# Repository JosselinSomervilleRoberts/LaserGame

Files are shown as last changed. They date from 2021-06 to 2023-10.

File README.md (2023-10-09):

# LaserGame

For more details about the project, please visit: https://josselinsomervilleroberts.github.io/


<br>

## Auteur

Josselin SOMERVILLE ROBERTS

<br><br>

## Câblage

### Pistolet

| Pin | Valeur du pin dans Arduino | Nom de la variable | Composant |
| --- | --- | --- | --- |
| D0  | 16 | buttons[0] | Bouton 1: **Gachette** |
| D1  | 5 | - | I2C Ecran |
| D2  | 4 | - | I2C Ecran |
| D3  | 0 | buttons[2] | Bouton 3: **Noir** |
| D4  | 2 | buttons[1] | Bouton 2: **Rouge** |
| D5  | 14 | laser | Laser de visée |
| D6  | 12 | kIrLed | Led IR de tir |
| D7  | 13 | df_player | Pin d'envoi de données au DF Player (le pin de réception n'est pas utilisé par manque de pins) |
| D8  | 15 | led | Led de connexion |
| A0  | A0 | - | Bouton 0: **Bleu** |

### Plastron

| Pin | Valeur du pin dans Arduino | Nom de la variable | Composant |
| --- | --- | --- | --- |
| D2  | 4 | ledPin | Bandeau Led |
| D4  | 2 | krecvPin | Récepteur IR |
| D5  | 14 | led1 | Led **Rouge** *(plastron allumé)* |
| D6  | 12 | led2 | Led **Verte** *(vivant)* |
| D7  | 13 | led3 | Led **Bleue** *(connexion)* |

## <br><br>

## Communication

### Communication IR

Les pistolets doivent être identifiables à la fois par **leur adresse MAC** mais également par **le code IR qu'ils envoient**. Comme tous les pistolets partagent les mêmes 3 premiers octets pour leurs adresses MAC, il suffit d'envoyer que les 3 derniers. On peut facilement envoyer 4 octets en IR, on envoie donc les 3 derniers octets de l'adresse MAC du pistolet suivit de ***0x66*** permettant d'identifier qu'il s'agit d'un pistolet du jeu.**

<br>

### Communcation WiFi

#### Structure des messages

Les messages sont seulement composés de :

- l'adresse MAC de l'expéditeur

- un identifiant *(idMessage)*

- une valeur *(value - optionnelle)*

#### Liste des messages

| idMessage ***(uint8_t)*** | value ***(uint32_t)*** | Expéditeur | Récepteur | Decription |
| --- | --- | --- | --- | --- |
| 1 | Couleur **hue** de la cible | Cible avant | Pistolet | Demande de nouvelle connexion. |
| 2 | **Confirmation :** - 1=acceptée ; <br/>- 2=refusée | Pistolet | Cible avant | **Réponse** à une demande de nouvelle connexion ***(id 1)***. |
| 3 | 3 derniers octets de l'adresse MAC du pistolet | Cible avant | Cible arrière | Indique à la cible secondaire de demander à se connecter à un pistolet (suite à une confirmation de connexion ***(id 2)***). |
| 4 | - | Cible avant / Cible arrière | Pistolet | Demande de reconnexion (notamment quand on rallume une cible). |
| 5 | Temps en secondes | Pistolet | Cible avant / Cible arrière | Vérification que la connexion pistolet - cible est toujours active. |
| 6 | Temps en seconde | Cible avant / Cible arrière | Pistolet | **Réponse** à demande de vérification de la validité de la connexion ***(id 5)***. La valeur ens econdes sert à vérifier qu'on obtient bien la confirmation de la denière demande. (si après une demande à *t=17s* on obtient une confirmation pour *t=13s*, il y a un problème : *lag de 4s.*). |
| 7 | - | Pistolet | Cible avant / Cible arrière | Demande de reconnexion (notamment quand onr allume le pistolet). |
| 8 | Couleur **hue** de la cible | Cible avant / Cible arrière | Pistolet | **Réponse** à la demande de reconnexion du pistolet ***(id 7)*** : la reconnexion ets acceptée. |
| 9 | Couleur **hue** de la cible | Pistolet | Cible avant / Cible arrière | Le pistolet a fait un choix d'équipe *(et donc les cibles doivent potentiellement changer de couleur)*. |
| 10 | 3 derniers octets de l'adresse MAC du pistolet qui a touché puis un octer qui vaut 1 si c'est la cible avant, 2 sinon | Cible avant / Cible arrière | Pistolet | Cible touchée. |
| 11 | - | Pistolet | Cible avant / Cible arrière | Mourir. |
| 12 | - | Pistolet | Cible avant / Cible arrière | Revivre. |
| 13 | - | Cible avant / Cible arrière | L'autre cible | Demande de si l'autre cible est connectée à un pistolet ou non *(si quand on rallume la cible, elle n'a pas de pistolet en mémoire, elle peut demander à l'autre cible si elle est déja connectée à un pistolet)*. |
| 14 | - 1SB: couleur **hue**<br/>- 2LSB(1/2): hasBeenConnected?<br/>- 2LSB(2/2): equipeChosen? | Cible avant / Cible arrière | L'autre cible | **Réponse** à la demande si la cible a été connectée à un pistolet ***(id 13)***. |
| 20 | Couleur **hue** de la cible | Pistolet | Cible avant / Cible arrière | Changement de couleur *(sans confirmation du choix d'équipe contrairement à **(id 9)**)*. |
| 30 | - 1: pour commencer<br/>- 2: pour finir | Pistolet **principal** | Autres pîstolets | Changement d'état de la partie. |
| 31 | - 1: pour commencer<br/>- 2: pour finir | Pistolet | Cible avant / Cible arrière | Changement d'état de la partie. |
| 35 | RANDOM JUNK ATM | Pistolet touché | Pistolet qui a touché | Avoir tué quelqu'un. |
| 40 | Nombre de respawns max | Pistolet **principal** | Autres pistolets | **Changement de règle:** nombre de respawns max. |
| 41 | Nombre de morts définitives max | Pistolet **principal** | Autres pistolets | **Changement de règle:** nombre de morts définitives max. |
| 42 | Temps de respawn ***(en secondes)*** | Pistolet **principal** | Autres pistolets | **Changement de règle:** temps de respawn. |
| 43 | Temps de jeu ***(en minutes)*** | Pistolet **principal** | Autres pistolets | **Changement de règle:** temps d'une partie. |
| 44 | - 0: Plastrons allumés<br/>- 1: Plastrons éteints | Pistolet **principal** | Autres pistolets | **Changement de règle:** allumage des lumières des plastrons. |
| 45 | - 0: Plastrons allumés<br/>- 1: Plastrons éteints | Pistolet | Cible avant / Cible arrière | Eteindre ou allumer la lumière des plastrons. |
| 50 | - | Pistolet | Cible avant / Cible arrière | Déconnexion. |
| 60 | Couleur **hue** de la cible | Pisotlet **admin** | Autres pistolets | **DOOM:** OS tous les adversaires (un joueur est considéré adversaire s'il a une couleur **hue** différente de celle envoyée par le pistolet admin) |

<br><br>

## Stockage des données

    Certaines données sont stockées dans la **mémoire EEPROM** afin d'être conservée même si la carte est éteinte. Cela sert notamment a restaurer la connexion si le pistolet ou une cible s'éteint et à s'assurer qu'un joueur ne triche pas en éteignant osn pistolet pour récupérer toute sa vie. Cela permet également de stocker les paramètres de la partie *(temps de respawn, nombre de respawns max, ...)*. Enfin certaines données ***statiques*** sont stockées dans cette mémoire *(id du pistolet, adresse MAC, numéro des musiques, ...)*. Cela permet de ne pas avoir à changer dans le programme certaines variables comme l'identifiant d'un pistolet et ainsi d'avoir un seul programme pour tous les pistolets et un autre pour toutes les cibles (avant et arrière).

    Le score était enregistré mais cette fonctionnalité n'est plus utilisée étant donnée que la comptabilisation du score est désactivée pour une meilleure réception des signaux IR.

    Il faut bien faire attention à ne pas enregistrer trop souvent des données dans la mémoire EEPROM car sa durée de vie est limitée (entre 100 000 et 1 000 000 d'enregistrements pour chaque octets).

<br>

### Pistolet

| Plage d'octets (inclus) | Variable stockée |
| --- | --- |
| 0 - 5 | **Adresse MAC** du pistolet |
| 6 - 11 | **Adresse MAC** de la dernière cible avant connectée |
| 12 - 17 | **Adresse MAC** de la dernière cible arrière connectée |
| 18 - 23 | **Adresse MAC** du dernier pistolet secondaire connecté ***UNUSED*** |
| 24 - 29 | **Adresse MAC** du pistolet de référence ***UNUSED*** |
| 30 | ID du pistolet |
| 31 | ID du pistolet principal *(référence)* ***UNUSED*** |
| 98 | **Etat partie :** Role *(principal / secondaire)*  ***UNUSED*** |
| 99 | **Etat partie :** ID de l'équipe |
| 100 | **Etat partie :** Partie commencée ? |
| 101 - 172 | **Score :** Pattern x8 :<br/>- 101: Nombre de tirs sur le joueur 1 - cible avant<br/>- 102: Nombre de tirs sur le joueur 1 - cible avant - pistolet secondaire<br/>- 103: Nombre de tirs sur le joueur 1 - cible arrière<br/>- 104: Nombre de tirs sur le joueur 1 - cible arrière - pistolet secondaire<br/>- 105: Nombre de fois touché par joueur 1 cible avant<br/>- 106: Nombre de fois touché par joueur 1 cible avant - pistolet secondaire<br/>- 107: Nombre de fois touché par joueur 1 cible arrière<br/>- 108: Nombre de fois touché par joueur 1 cible arrière - pistolet secondaire<br/>***UNUSED*** |
| 189 | **Setting :** Admin ? |
| 190 | **Cheat :** Invincible ? |
| 191 | **Cheat :** Munitions illimités ? |
| 192 | **Cheat :** Tir rapide ? **NOT WORKING** |
| 193 | **Règle :** Nombre de respawns max |
| 194 | **Règle :** Nombre de morts définitives max |
| 195 | **Règle :** Délai de respawn *(en secondes)* |
| 196 | **Règle :** Duréed'une partie *(en minutes)* |
| 197 | **Règle :** Lumières des plastons allumées ? |
| 198 | **Etat partie :** Nombre de vies du joueur |
| 199 | **Etat partie :** Nombre de respawns restants du joueur |
| 200 | **Etat partie :** Nombre de morts définitives restantes du joueur |
| 201 - 229 | Numéro des 28 musiques ***(la numérotation diffère pour certains DF players, d'ou l'intéret)*** |

<br>

### Plastron

| Plage d'octets (inclus) | variable stockée |
| --- | --- |
| 0 - 5 | **Adresse MAC** de la cible |
| 6 - 11 | **Adresse MAC** de l'autre cible |
| 12 - 17 | **Adresse MAC** du dernier pistolet connecté |
| 18 - 23 | **Adresse MAC** du dernier psitolet secondaire connecté ***UNUSED*** |
| 24 | Type de la cible<br/>- 1 : AVANT<br/>- 2 : ARRIERE |
| 25 | Couleur **hue** |

<br><br>

## Musiques et effets sonores

    Les effets sonores sont gérés par la carte DF Player qui lit les fichiers MP3 stockés sur la carte SD contenue dans le pistolet. 

    Pour une raison étonnante, certains DF Player ne lisent pas les fichiers dans le bon ordre (normalement *myDFPlayer.play(1)* est censé jouer le morceau *0001.wav* mais ce n'est pas le cas pour tous les modèles). C'est pour ça que l'ordre des musiques est stocké dans le mémoire EEPROM pour chaque pistolet.

    Voici la liste des effets sonores disponibles :

| Fichier *(.wav)* | Effet sonore |
| --- | --- |
| 0001 | Tirer pistoler |
| 0002 | Tirer shotgun |
| 0003 | Tirer laser *(2 s)* |
| 0004 | Tirer pistolet - plus de munitions |
| 0005 | Tirer shotgun - plus de munitions  |
| 0006 | Tirer laser - plus de munitions |
| 0007 | Recharger pistolet |
| 0008 | Recharger shotgun |
| 0009 | Recharger laser |
| 0010 | Toucher ennemi |
| 0011 | Toucher allié |
| 0012 | Perdre une vie |
| 0013 | Mourir |
| 0014 | Revivre |
| 0015 | Gagner une vie |
| 0016 | Le médecin fait revivre quelqu'un  |
| 0017 | Mort définitive |
| 0018 | Début partie |
| 0019 | Fin partie |
| 0020 | Power up 1 |
| 0021 | Power down 1 |
| 0022 | Power up 2 |
| 0023 | Power down 2 |
| 0024 | Power up 3 |
| 0025 | Power down 3 |
| 0026 | Power up 4 |
| 0027 | Power down 4 |
| 0028 | Mort 2 |

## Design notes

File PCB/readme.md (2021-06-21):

# PCB Files

These files were designed on **EasyEDA** by myself.

## SuperCharger

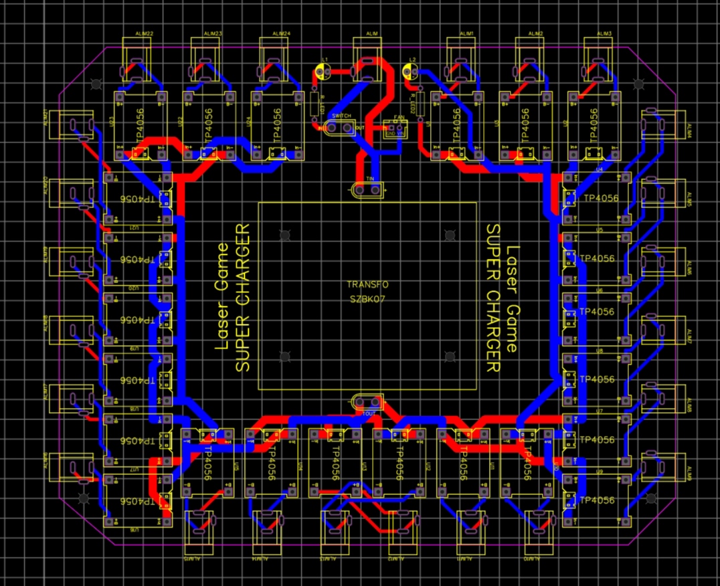
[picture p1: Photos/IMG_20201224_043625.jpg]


## Gun

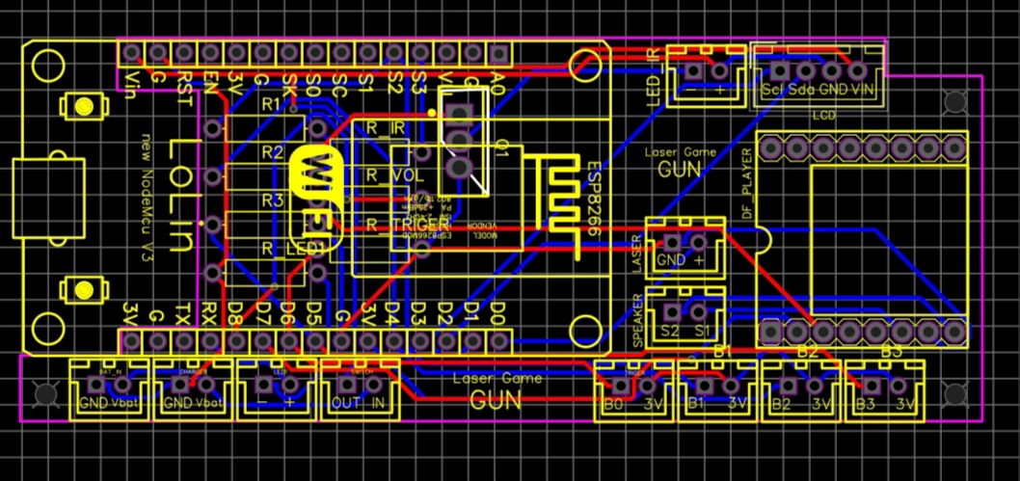
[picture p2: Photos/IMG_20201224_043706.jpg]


## Plastron

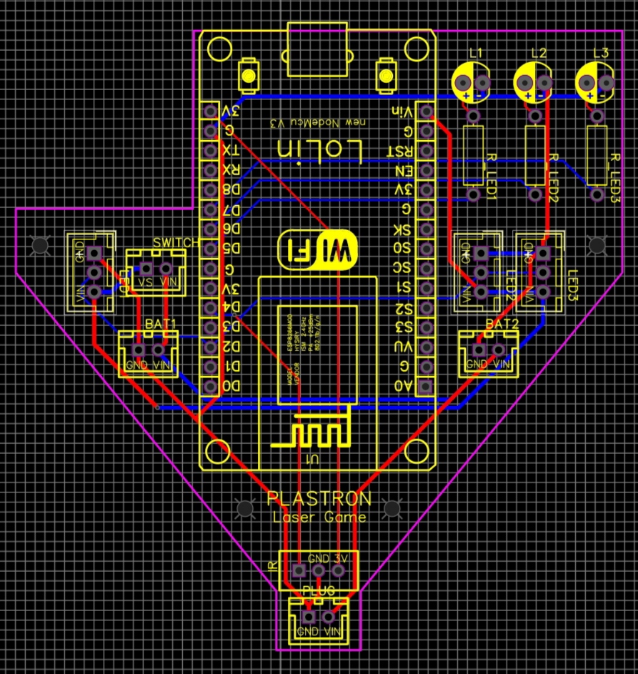
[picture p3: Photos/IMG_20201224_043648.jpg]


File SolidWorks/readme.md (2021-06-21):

# Solidworks Files

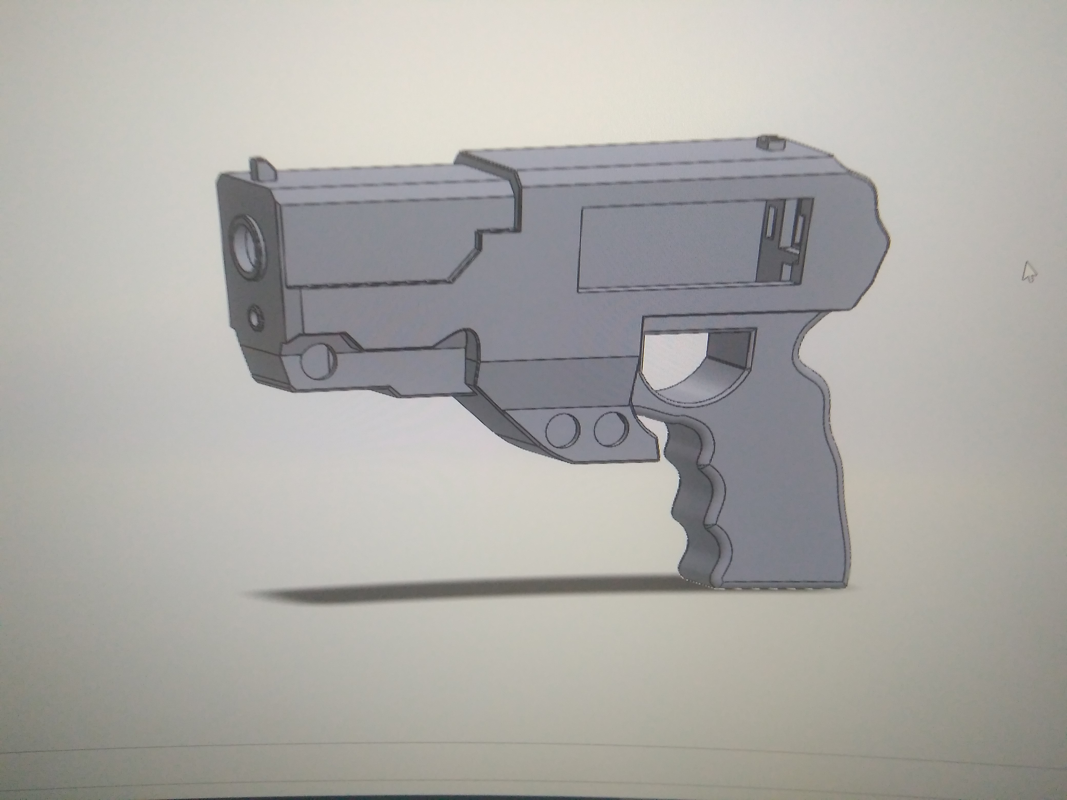
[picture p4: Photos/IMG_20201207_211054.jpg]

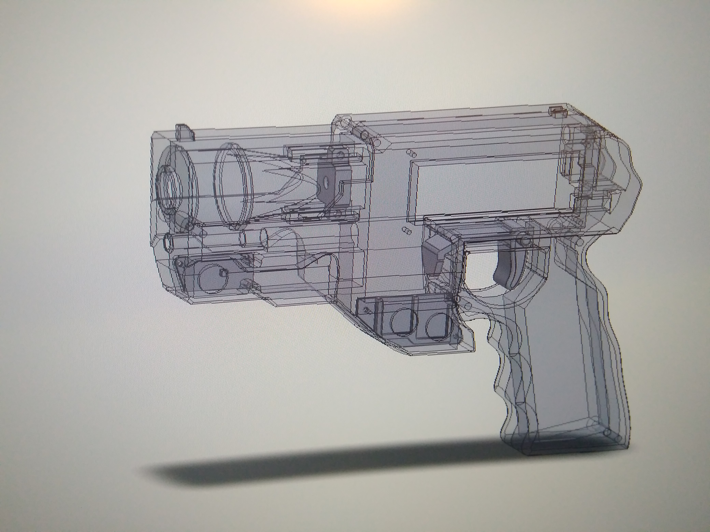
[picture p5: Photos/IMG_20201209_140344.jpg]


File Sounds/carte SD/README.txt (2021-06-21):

0001. Shoot pistolet - 4
0002. Shoot shotgun  - 5
0003. Shoot laser (2sec) - 6

0004. Shoot pistolet - plus de munitions - 7
0005. Shoot shotgun  - plus de munitions - 8
0006. Shoot laser - plus de munitions - 9

0007. Recharger pistolet - 10
0008. Recharger shotgun  - 11
0009. Recharger laser    - 12

0010. Toucher quelqu'un   - 13
0011. Toucher allié       - 14
0012. Perdre une vie      - 15
0013. Mourir              - 16
0014. Revivre             - 17
0015. Gagner une vie      - 18
0016. Medecin fait revivre quelqu'un - 19
0017. Mort du roi                    - 20

0018. Début partie                   - 21
0019. Fin partie                     - 22

0020. Power up 1    - 23
0021. Power down 1  - 24
0022. Power up 2    - 25
0023. Power down 2  - 26
0024. Power up 3    - 27
0025. Power down 3  - 28
0026. Power up 4 - 1
0027. Power down 4 - 2
0028. Mort 2 - 3

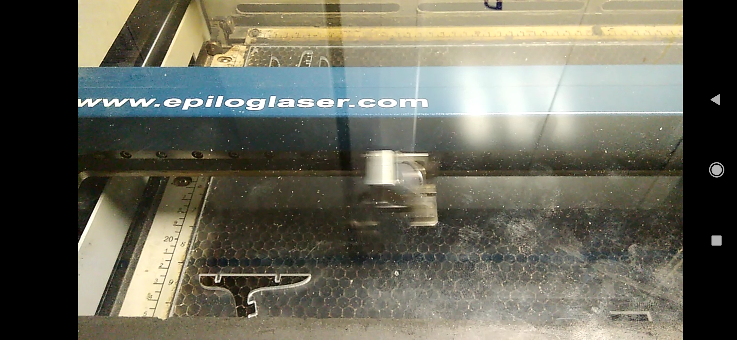
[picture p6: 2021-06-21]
Photos/Screenshot_2020-12-24-04-1.jpg

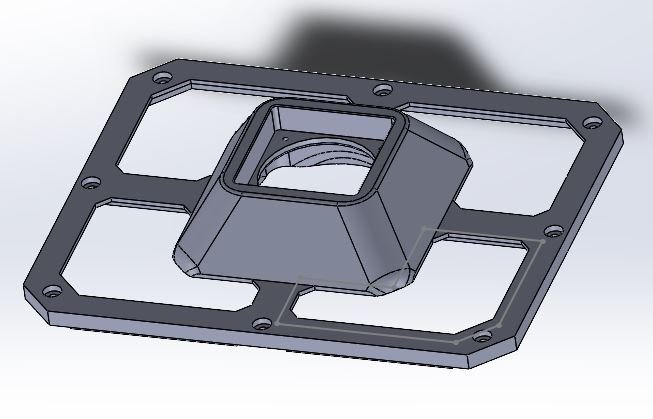
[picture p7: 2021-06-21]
Photos/couvercle_chargeur.JPG

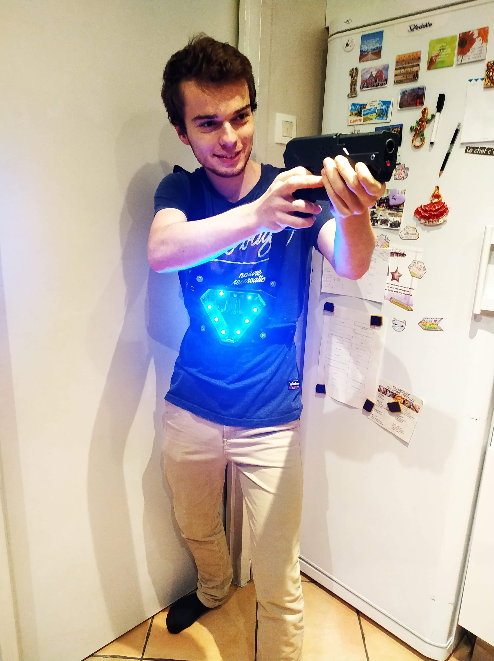
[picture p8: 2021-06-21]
Photos/received_430355725015219.jpeg

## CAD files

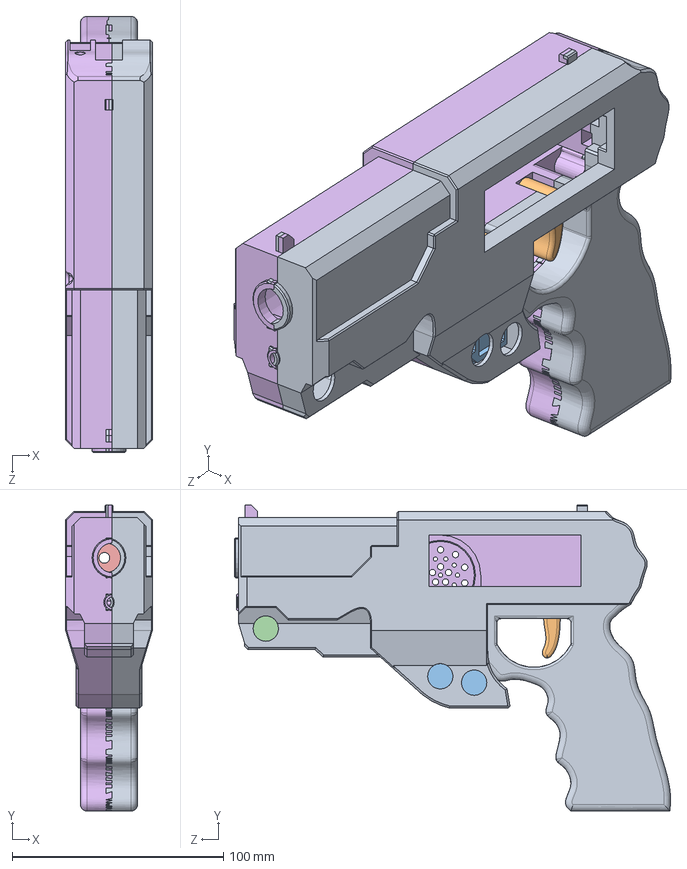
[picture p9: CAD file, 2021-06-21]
SolidWorks/pistolet v3/Assemblage_complet.SLDASM
41.0 x 144.7 x 206.3 mm
pistolet_cote_circuit
gachette_v3
plaque_interrupteur_crosse
plaque_interrupteur_canon
coulisseau_v3
pistolet_cote_rien

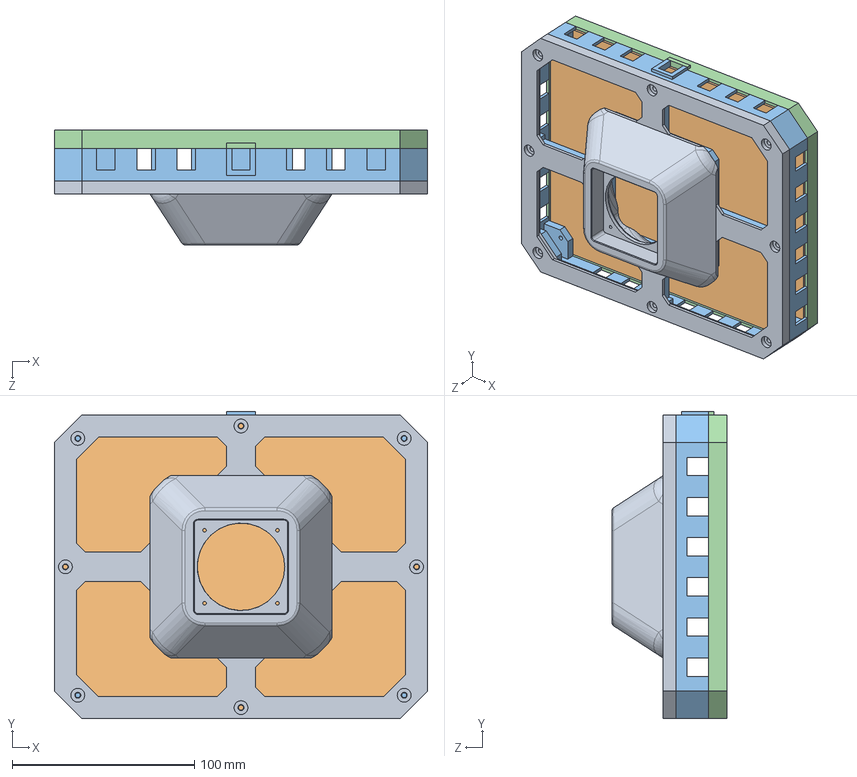
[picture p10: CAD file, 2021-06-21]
SolidWorks/chargeur v1/Assemblage1.SLDASM
204.5 x 168.4 x 63.0 mm
couvercle
pcb
piece_milieu
plaque_dessous

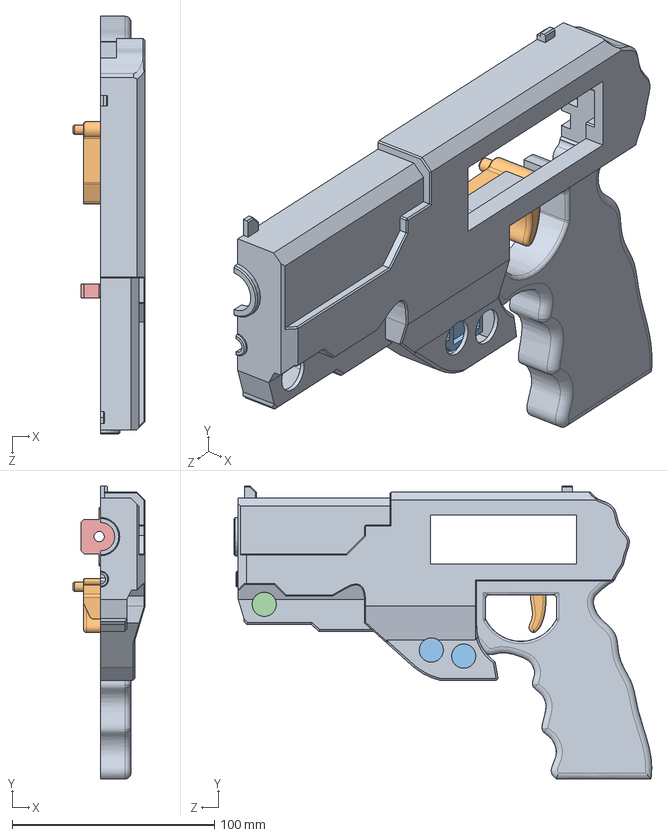
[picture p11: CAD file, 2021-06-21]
SolidWorks/pistolet v3/Assemblage_en_coupe.SLDASM
35.7 x 144.7 x 206.3 mm
pistolet_cote_circuit
gachette_v3
plaque_interrupteur_crosse
plaque_interrupteur_canon
coulisseau_v3

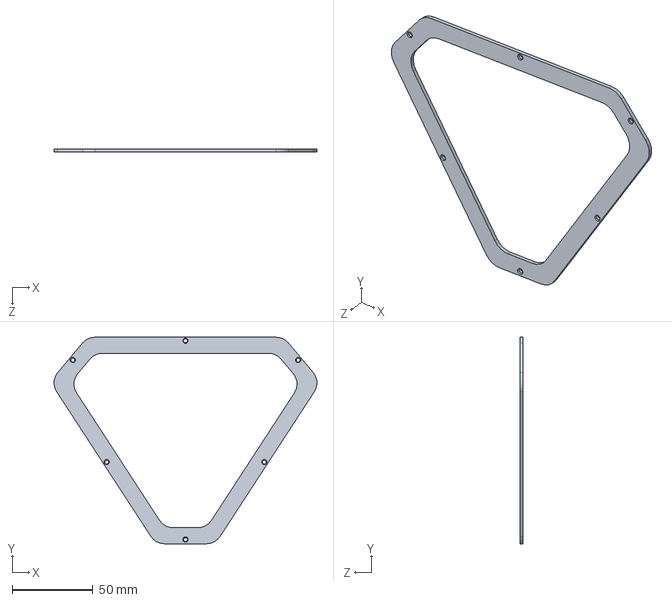
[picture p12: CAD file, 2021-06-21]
SolidWorks/plastron v1/maintien_plexi_v3.SLDPRT
163.3 x 128.3 x 2.00 mm

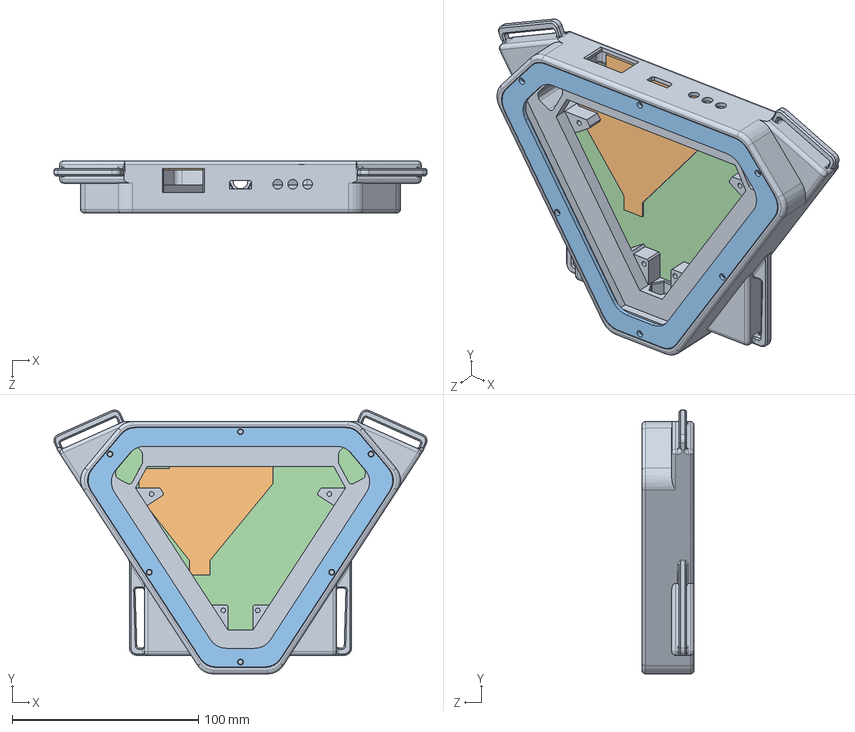
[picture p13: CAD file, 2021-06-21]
SolidWorks/plastron v1/Assemblage.SLDASM
200.0 x 141.6 x 28.0 mm
plastron_avant
pcb_plastron_v1
maintien_plexi
plexiglass

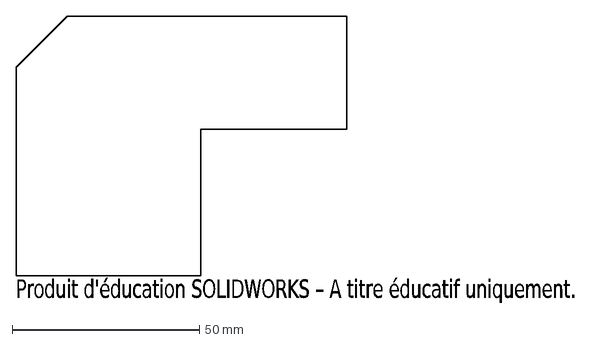
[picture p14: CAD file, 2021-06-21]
SolidWorks/chargeur v1/plexiglass_chargeur.DXF
Produit d'éducation SOLIDWORKS – A titre éducatif uniquement.

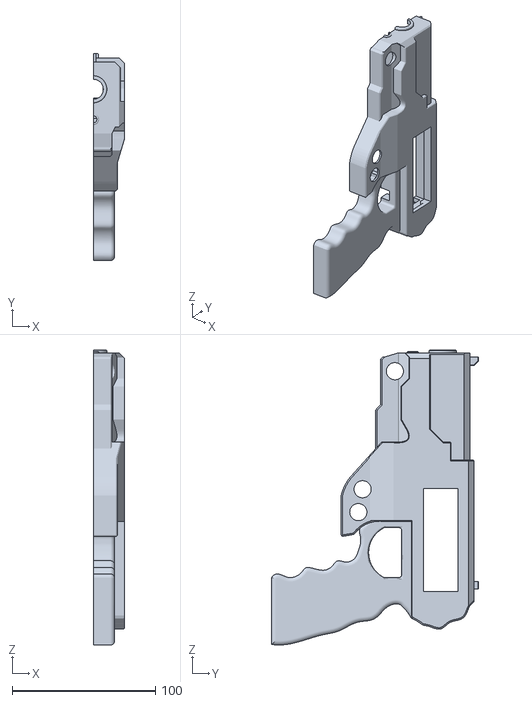
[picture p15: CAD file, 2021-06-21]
SolidWorks/pistolet v3/pistolet_cote_circuit_corrige.STL
22.0 x 144.7 x 206.3

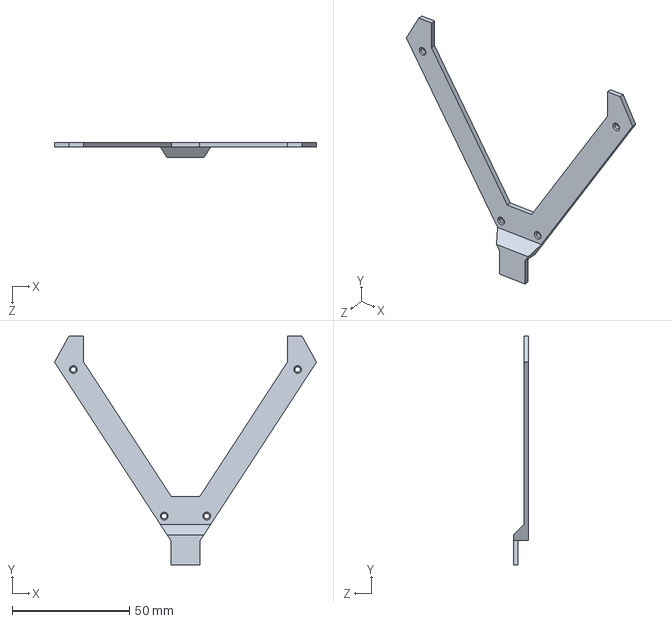
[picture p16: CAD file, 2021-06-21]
SolidWorks/plastron v1/cache_batterie_v2.SLDPRT
111.5 x 97.4 x 6.50 mm

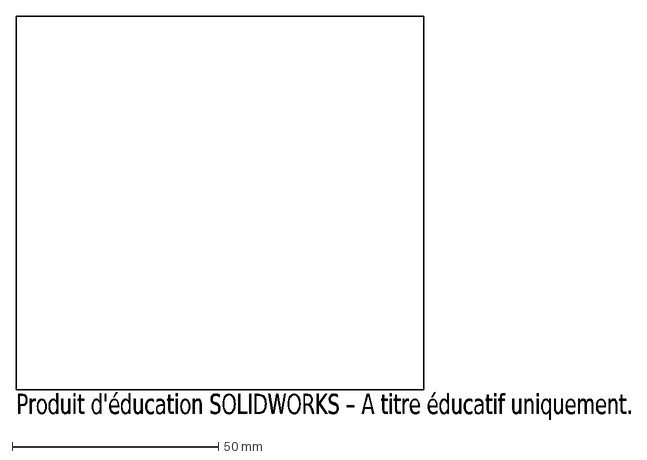
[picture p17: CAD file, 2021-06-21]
SolidWorks/test_dxf.DXF
Produit d'éducation SOLIDWORKS – A titre éducatif uniquement.

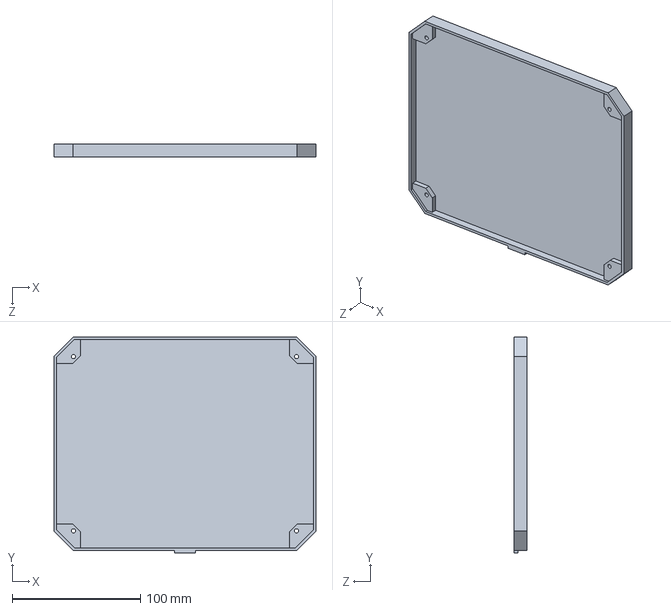
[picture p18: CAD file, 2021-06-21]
SolidWorks/chargeur v1/plaque_dessous.SLDPRT
204.5 x 168.4 x 10.0 mm

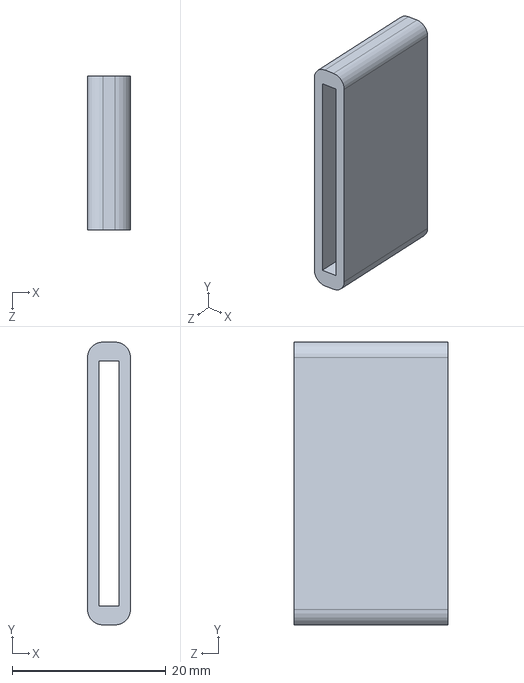
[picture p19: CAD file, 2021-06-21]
SolidWorks/clip_sangle_v2.SLDPRT
5.60 x 36.8 x 20.0 mm

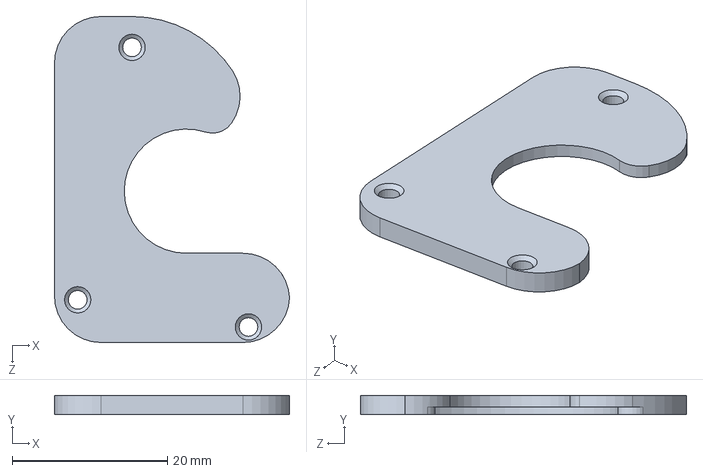
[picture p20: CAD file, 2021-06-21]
SolidWorks/pistolet v3/plaque_enceinte.SLDPRT
30.3 x 2.50 x 42.0 mm

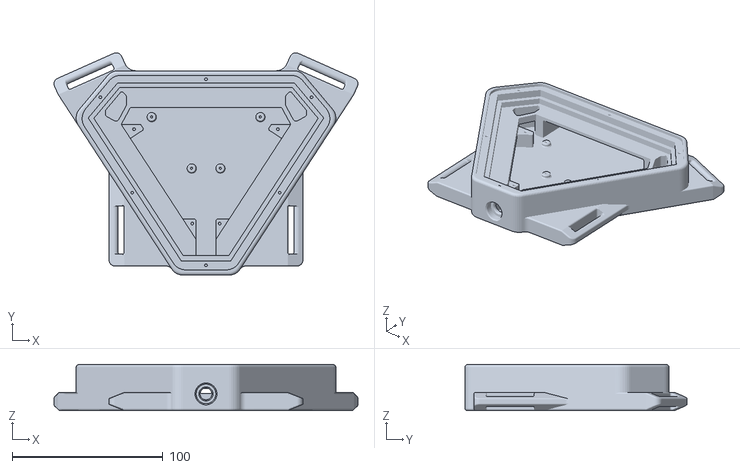
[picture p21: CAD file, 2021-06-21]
SolidWorks/plastron v1/plastron_avant_16_01.STL
201.4 x 147.3 x 30.5

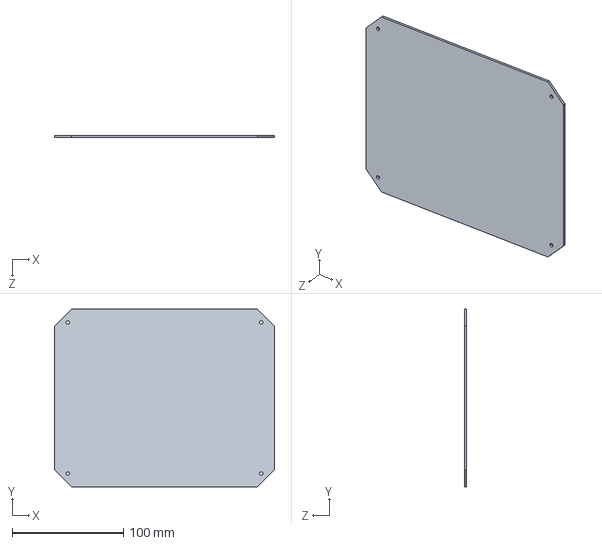
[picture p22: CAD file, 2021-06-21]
SolidWorks/chargeur v1/pcb.SLDPRT
198.1 x 160.0 x 2.00 mm

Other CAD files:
SolidWorks/plastron v1/maintien_plexi.SLDPRT
SolidWorks/clip_sangle.SLDPRT
SolidWorks/plastron v1/plastron_avant.SLDPRT
SolidWorks/pistolet v3/gachette_v4.STL
SolidWorks/chargeur v1/couvercle.SLDPRT
SolidWorks/chargeur v1/couvercle.STL
SolidWorks/chargeur v1/piece_milieu.SLDPRT
SolidWorks/chargeur v1/piece_milieu.STL
SolidWorks/chargeur v1/plaque_dessous.STL
SolidWorks/chargeur v1/plexiglass.SLDPRT
SolidWorks/clip_sangle.STL
SolidWorks/clip_sangle_v2.STL
SolidWorks/pistolet v1/canon_1.SLDPRT
SolidWorks/pistolet v1/canon_1.STL
SolidWorks/pistolet v1/canon_2.SLDPRT
SolidWorks/pistolet v1/canon_2.STL
SolidWorks/pistolet v1/coullisseau_double.SLDPRT
SolidWorks/pistolet v1/coullisseau_double.STL
SolidWorks/pistolet v1/coullisseau_simple.SLDPRT
SolidWorks/pistolet v1/coullisseau_simple.STL
SolidWorks/pistolet v2/Assemblage1.SLDASM
SolidWorks/pistolet v2/canon_inf.SLDPRT
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

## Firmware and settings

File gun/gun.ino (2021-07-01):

#include <Arduino.h>
#include <LiquidCrystal_I2C.h>
#include "SoftwareSerial.h"    // pour les communications series avec le DFplayer
#include <DFPlayerMini_Fast.h>  // bibliotheque pour le DFPlayer
//#include "DFRobotDFPlayerMini.h"
#include <IRremoteESP8266.h>
#include <IRsend.h>
#include <EEPROM.h>
#include <ESP8266WiFi.h>
#define EEPROM_SIZE 256
#include <espnow.h>

#define ledBlinkWainting 150
#define ledBlinkOneConnected 500

#define TIME_WAIT_MAX_CHECK_CONNECTION 750
#define TIME_WAIT_CHECK_CONNECTION 350
#define TIME_WAIT_BEFORE_SENDING_AGAIN 100

#define TIME_IMMUNE 200

const String softwareVersion = "2.7";


// PINS DEFINITION
const uint8_t kIrLed = 12;    // D6
const uint8_t laser = 14;     // D5
const uint8_t led = 15;       // D8
const uint8_t buttons[] = {16, 2, 0}; // D0, D4, D3
const uint8_t df_player = 13; // D7
// D1 et D2 utilisés pour la liaison I2C avec l'écran
// Le dernier bouton est sur l'entrée analogique A0


// Parametres pour l'affichage et le son
const int lcdColumns = 16;
const int lcdRows = 2;
int volume = 22;
uint32_t timeLedLastUpdate = 0;
bool ledState = false;


// Définition des objets
IRsend irsend(kIrLed);  // Set the GPIO to be used to sending the message.
SoftwareSerial mySoftwareSerial(17,df_player); // RX, TX ( wemos D2,D8 ou 4,15 GPIO )  ou Tx,RX ( Dfplayer )
DFPlayerMini_Fast  myDFPlayer;  // init player
//DFRobotDFPlayerMini myDFPlayer;
LiquidCrystal_I2C lcd(0x27, lcdColumns, lcdRows); 


// Variables
long last_update = 0;
bool buttonStates[4] = {false, false, false, false};
bool waitingConnectionAnswer = false;

uint8_t addressSelf[] = {0x00, 0x00, 0x00, 0x00, 0x00, 0x00};
uint8_t addressReceived[] = {0x84, 0xCC, 0xA8, 0x00, 0x00, 0x00};
uint8_t addressCibleAvant[] = {0x84, 0xCC, 0xA8, 0x00, 0x00, 0x00};
uint8_t addressCibleArriere[] = {0x84, 0xCC, 0xA8, 0x00, 0x00, 0x00};
bool connectedCibleAvant = false;
bool connectedCibleArriere = false;
uint32_t lastConnectionCheckAvant = 0;
uint32_t lastConnectionCheckArriere = 0;
uint32_t lastConnectionConfirmationAvant = 0;
uint32_t lastConnectionConfirmationArriere = 0;
uint32_t lastCheckValueAvant = 0;
uint32_t lastCheckValueArriere = 0;
bool hasBeenConnectedCible = false;

uint8_t redondanceEnvoi = 5;
uint8_t delaiEnvoi = 10;
int nbEnvoisRestants = 0;
bool entrainEnvoyer = false;


// Pour le jeu
int munitions = 40;
bool isReloading = false;
uint32_t timeStartedReloading = 0;
int timeReload[] = {2000, 1000, 3000};
int munitionsMax[] = {40, 3, 50};
int soundShoot[] = {1,2,3};
int soundReload[] = {7,8,9};
int soundEmpty[] = {4,5,6};
uint8_t musique[28];
long timeBetweenShots[] = {100, 1000, 0};
long timeLastShot = 0;
long timeLastBeingSemiShot = 0;
int weapon = 0;
bool isShootingLoop = false;
bool equipeChosen = false;
uint8_t hue = 0;
bool isImmune = false;
long timeStartedBeingImmune = 0;
  

// Stats
int score = 0;
int vie = 0;
uint8_t kills = 0;
uint8_t deaths = 0;
bool vivant = true;
long timeDeath = 0;
uint8_t player = 1;
uint8_t role = 1; // 1 GUN Principal, 2 Secondaire
int respawnsRestants = 0;

// Etat du jeu
bool started = false;
long timeGameStarted = 0;

// Affichage
bool needRefreshAll = true;
bool needRefreshScore = false;
bool needRefreshWeapon = false;
bool needRefreshMunitions = false;
int lastPourcent = 100;


// Score
uint8_t s_nbTirsAvant[] = {0,0,0,0,0,0,0,0};
uint8_t s_nbTirsAvantSecondaire[] = {0,0,0,0,0,0,0,0};
uint8_t s_nbTirsArriere[] = {0,0,0,0,0,0,0,0};
uint8_t s_nbTirsArriereSecondaire[] = {0,0,0,0,0,0,0,0};
uint8_t s_nbTouchesAvant[] = {0,0,0,0,0,0,0,0};
uint8_t s_nbTouchesAvantSecondaire[] = {0,0,0,0,0,0,0,0};
uint8_t s_nbTouchesArriere[] = {0,0,0,0,0,0,0,0};
uint8_t s_nbTouchesArriereSecondaire[] = {0,0,0,0,0,0,0,0};
uint8_t s_equipe[] = {0,0,0,0,0,0,0,0};


// Rules
bool r_friendlyFire = true;
int r_friendlyShootScore = - 50;
int r_ennemyShootScore = +100;
int r_friendlyBeingShotScore = 0;
int r_ennemyBeingShotScore = -50;
long r_timeRespawn = 8000;
uint8_t r_nbMortsDefinitives = 255;
uint8_t r_viesMax = 1;
bool r_regen = false;
long r_timeRegen = 30000;
long r_timeGameDuration = 1200000;
uint8_t r_nbRespawns = 3;
long r_timeStartSemiRegen = 1500;
bool light_on = true;

uint8_t tueur = 0;
uint8_t cibleTueur = 0;
bool tue = false;
long timeStartedAffichageTue = 0;
long dureeAffichageTue = 0;
bool afficherTue = false;
bool tueurAllie = false;

uint8_t nb_fois_pistolet_eteint = 0;



// ADMIN Mode
bool admin = false;
bool enteringCodeMenu = false;
bool inAdminMenu = false;
bool inCodeMenu = false;
uint32_t timeStartedEnteringCodeMenu = 0;
uint32_t timeToEnterCodeMenu = 1500;
uint8_t code[] = {2,2,2,3,0,3,2,0,3,3,2};
uint8_t codeTape[16] = {0,0,0,0,0,0,0,0,0,0,0,0,0,0,0,0};
uint8_t longueurCodeTape = 0;

bool invincible = false;
bool munitions_illim = false;
bool rapidFire = false;


typedef struct struct_message {
  uint8_t idMessage;
  uint32_t value;
} struct_message;

// Create a struct_message called myData
struct_message myData;


void deconnecter() {
  if(connectedCibleAvant) {
    myData.idMessage = 50;
    myData.value = 0;
    esp_now_send(addressCibleAvant, (uint8_t *) &myData, sizeof(myData));
  }

  if(connectedCibleArriere) {
    myData.idMessage = 50;
    myData.value = 0;
    esp_now_send(addressCibleArriere, (uint8_t *) &myData, sizeof(myData));
  }

  waitingConnectionAnswer = false;
  connectedCibleAvant = false;
  connectedCibleArriere = false;
  lastConnectionCheckAvant = 0;
  lastConnectionCheckArriere = 0;
  lastConnectionConfirmationAvant = 0;
  lastConnectionConfirmationArriere = 0;
  lastCheckValueAvant = 0;
  lastCheckValueArriere = 0;
  hasBeenConnectedCible = false;
  equipeChosen = false;
}




void OnDataRecv(uint8_t * mac, uint8_t *incomingData, uint8_t len) {
  memcpy(&myData, incomingData, sizeof(myData));
  memcpy(&addressReceived, mac, sizeof(addressReceived));

  if(myData.idMessage != 6) {
    Serial.println("-> Wifi message received");
    Serial.print("- id = ");
    Serial.println(myData.idMessage);
    Serial.print("- value = ");
    Serial.println(myData.value, HEX);
  }

  bool cestCibleAvant = true;
  for(int i=0; i<6; i++) {
    if(addressCibleAvant[i] != addressReceived[i])
      cestCibleAvant = false;
  }

  bool cestCibleArriere = true;
  for(int i=0; i<6; i++) {
    if(addressCibleArriere[i] != addressReceived[i])
      cestCibleArriere = false;
  }
  



  if(myData.idMessage == 1) { // Demande de nouvelle connexiond e la part d'une cible avant
    for(int i=0; i<6; i++)
      Serial.println(addressReceived[i], HEX);

      if(not(connectedCibleAvant)) {
        if(not(connectedCibleArriere)) {
          String couleur = "No color";
          if(myData.value == 0)
            couleur = "rouge";
          else if(myData.value == 32)
            couleur = "jaune";
          else if(myData.value == 64)
            couleur = "vert c";
          else if(myData.value == 96)
            couleur = "vert";
          else if(myData.value == 128)
            couleur = "ciel";
          else if(myData.value == 160)
            couleur = "bleu";
          else if(myData.value == 192)
            couleur = "violet";
          else if(myData.value == 224)
            couleur = "rose";
          hue = myData.value;
  
          
          EEPROM.write(200,nb_fois_pistolet_eteint);
          EEPROM.commit();
          lcd.clear();
          lcd.setCursor(0, 0);
          lcd.print("Connect " + couleur + " ?");
          lcd.setCursor(0, 1);
          lcd.print("Noir:No Bleu:Oui");
    
          waitingConnectionAnswer = true;

          if(not(hasBeenConnectedCible)) {
            EEPROM.write(100, 0);
            started = false;
        }
        }
      }
      else {
        // Sinon c'est la cible arriere qui se connecte pour la premiere fois
        for(int i=0; i<6; i++) {
          addressCibleArriere[i] = addressReceived[i];
          EEPROM.write(12+i, addressCibleArriere[i]);
        }
        EEPROM.commit();
            
        esp_now_add_peer(addressReceived, ESP_NOW_ROLE_COMBO, 1, NULL, 0);
        myData.idMessage = 2; // ID pour dire qu'on demande a se connecter
        myData.value = 1; // PAS DE VALEUR
        esp_now_send(addressReceived, (uint8_t *) &myData, sizeof(myData));
        connectedCibleArriere = true;
        hasBeenConnectedCible = true;
        needRefreshAll = true;
      }
  }

  else if(myData.idMessage == 4) { // Demande de reconnexion de la part d'une cible
    if((cestCibleAvant and (started or hasBeenConnectedCible)) or (cestCibleArriere and (started or hasBeenConnectedCible))) {
      Serial.println("RECONNEXION");

      if(cestCibleAvant) {
        connectedCibleAvant = true;
        hasBeenConnectedCible = true;
        needRefreshAll = true;
        lastConnectionCheckAvant = millis();
        lastConnectionConfirmationAvant = millis();
        if(equipeChosen) {
          myData.idMessage = 9;
          myData.value = hue;
          esp_now_send(addressCibleAvant, (uint8_t *) &myData, sizeof(myData));
        }
        else {
          if(not(hasBeenConnectedCible))
            hue = myData.value;
        }
      }

      if(cestCibleArriere) {
        connectedCibleArriere = true;
        hasBeenConnectedCible = true;
        needRefreshAll = true;
        lastConnectionCheckArriere = millis();
        lastConnectionConfirmationArriere = millis();
        if(equipeChosen) {
          myData.idMessage = 9;
          myData.value = hue;
          esp_now_send(addressCibleArriere, (uint8_t *) &myData, sizeof(myData));
        }
        else{
          if(not(hasBeenConnectedCible))
            hue = myData.value;
        }
      }

      myData.idMessage = 2; // ID pour dire qu'on confirme la connexion
      myData.value = 1; // Accepter
      esp_now_send(addressReceived, (uint8_t *) &myData, sizeof(myData));
    }
  }

  else if(myData.idMessage == 6) { // Réponse d'une cible à la confirmation de connexion
    if(cestCibleAvant and (lastCheckValueAvant == myData.value))
      lastConnectionConfirmationAvant = millis();
    else if(cestCibleArriere and (lastCheckValueArriere == myData.value))
      lastConnectionConfirmationArriere = millis();
  }

  else if(myData.idMessage == 8) { // La cible accepte la demande de reconnexion effectuée par le pistolet
    if(cestCibleAvant or cestCibleArriere) {
      Serial.println("RECONNEXION");
      started = (EEPROM.read(100) == 1);

      if((millis() < 5000) and started and ((cestCibleAvant and connectedCibleArriere) or (connectedCibleAvant and not(cestCibleAvant)))){
        recupererParametres();
        munitions = 0;
        vie = EEPROM.read(198);
        respawnsRestants = EEPROM.read(199);
        nb_fois_pistolet_eteint = EEPROM.read(200);
        
        if(vie == 0) {
          if(respawnsRestants > 0) {
            respawnsRestants--;
            vie = r_viesMax;
            EEPROM.write(199,respawnsRestants);
            EEPROM.write(198,vie);
            EEPROM.commit();
            
            myData.idMessage = 12;
            myData.value = 0; // VALEUR ARBITRAIRE
            esp_now_send(addressCibleAvant, (uint8_t *) &myData, sizeof(myData));
            esp_now_send(addressCibleArriere, (uint8_t *) &myData, sizeof(myData));
          }
          else
          {   
            if(nb_fois_pistolet_eteint < r_nbMortsDefinitives) {
              nb_fois_pistolet_eteint++;
              respawnsRestants = r_nbRespawns;
              vie = r_viesMax;
              EEPROM.write(198,vie);
              EEPROM.write(199,respawnsRestants);
              EEPROM.write(200,nb_fois_pistolet_eteint);
              EEPROM.commit();
              
              myData.idMessage = 12;
              myData.value = 0; // VALEUR ARBITRAIRE
              esp_now_send(addressCibleAvant, (uint8_t *) &myData, sizeof(myData));
              esp_now_send(addressCibleArriere, (uint8_t *) &myData, sizeof(myData));
              myDFPlayer.play(musique[16-1]);
            }
            else {
              vivant = false;
            }
          }
        }
      }
      
      myData.idMessage = 2; // ID pour dire qu'on confirme la connexion
      myData.value = 1; // Accepter
      esp_now_send(addressReceived, (uint8_t *) &myData, sizeof(myData));
      sendParametersCibles();

      if(cestCibleAvant) {
        connectedCibleAvant = true;
        hasBeenConnectedCible = true;
        needRefreshAll = true;
        lastConnectionCheckAvant = millis();
        lastConnectionConfirmationAvant = millis();
        //hue = myData.value; // ERROR : Y A UN PROBLEME C EST DESACTIVE
      }

      if(cestCibleArriere) {
        connectedCibleArriere = true;
        hasBeenConnectedCible = true;
        needRefreshAll = true;
        lastConnectionCheckArriere = millis();
        lastConnectionConfirmationArriere = millis();
        //hue = myData.value; // ERROR : Y A UN PROBLEME C EST DESACTIVE
      }

      if(not(vivant)) {
        // On dit au cibles de mourir
        myData.idMessage = 11;
        myData.value = 0; // VALEUR ARBITRAIRE
        esp_now_send(addressCibleAvant, (uint8_t *) &myData, sizeof(myData));
        esp_now_send(addressCibleArriere, (uint8_t *) &myData, sizeof(myData));
      }
    }
  }
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
void loop() {
  //Serial.println("hue = " + String(hue));
  if(entrainEnvoyer) sendSingleTimeParametersCibles();
  
  // ADMIN Mode
  if(inAdminMenu)
    menuAdmin();
  else if(inCodeMenu) {
    if(admin) {
      inCodeMenu = false;
      inAdminMenu = true;
    }
    else
      menuCode();
  }
  else if((analogRead(0) >= 100) and not(digitalRead(2)) and not(digitalRead(3))) {
    digitalWrite(laser, LOW);
    if(enteringCodeMenu) {
      if(millis() - timeStartedEnteringCodeMenu > timeToEnterCodeMenu*(1.0-0.7*admin)) {
        inCodeMenu = true;
        enteringCodeMenu = false;
        needRefreshAll = true;
        buttonStates[0] = true;
        buttonStates[2] = true;
        buttonStates[3] = true;
      }
    }
    else {
      enteringCodeMenu = true;
      timeStartedEnteringCodeMenu = millis();
      needRefreshAll = true;
    }
  }
  else if(enteringCodeMenu) {
    enteringCodeMenu = false;
    needRefreshAll = true;
  }
  else {
    digitalWrite(laser, ((vivant) and (checkButtonPressed(2))));
  }

  // Si on est en attente de connexion affiche quiv eut se connecter et le choix d'accepter ou de refuser
  // Si on est pas en attente de connexion gère l'affichage de la LED
  verifierConnexion();
  gererAttenteDeConnexion();
  


  if(connectedCibleAvant and connectedCibleArriere and not(equipeChosen))
    choixEquipe();

  if(equipeChosen and not(started)) {
    affichage();

    if(!checkButtonPressed(2)) { // Cette condition sert à rentrer plus facilement dans le menu admin
      if(admin) {
        if(checkButtonPress(3)) { // Noir
          chooseRules();
          needRefreshAll = true;
        }
        if(checkButtonPress(0)) {// Bleu
          if(chooseBinary("Demarrer partie?", true)) {
            sendParameters();
            uint8_t adressGuns[] = {0x32, 0x32, 0x32, 0x32, 0x32, 0x00};
            for(int p=1; p<=9; p++) {
              if(p != player) {
                adressGuns[5] = p;
                myData.idMessage = 30;
                myData.value = 1;
                esp_now_send(adressGuns, (uint8_t *) &myData, sizeof(myData));
                delay(5);
              }
            }
            startGame();
          }
          needRefreshAll = true;
        }
      }
      else {
        if(checkButtonPress(3)) { // Noir
          equipeChosen = false;
          choixEquipe();
        }
      }
    }

    delay(20);
    return;
  }

  // ============= GERE les actions des 4 boutons ================ //
  if((vivant) and not(enteringCodeMenu)) {
    if((checkButtonPress(1)) and (millis() - timeLastShot >= (1.0 - 0.7*rapidFire)*timeBetweenShots[weapon]))
      shoot();    
    else if(checkButtonPress(3))
      startReload();//changeWeapon();
    else if(checkButtonPress(0))
      startReload();   

    // Gère la fin du chargement
    if (isReloading) {
      if(millis() - timeStartedReloading >= timeReload[weapon])
        finishReload();
    }

    // Pour le laser
    if((weapon==2) and isShootingLoop and not(buttonStates[1])) {
      isShootingLoop = false;
      myDFPlayer.pause();
    }
    if(isShootingLoop) {
      irsend.sendNEC(0x0000866 + pow(16,6)*player + (1+weapon)*pow(16,5)*(connectedCibleAvant and connectedCibleArriere) + role*pow(16,4) + uint8_t(hue/32.0)*pow(16,3));
      delay(15);
    }
  }
  // ============================================================ //
    

  // Rafraichit l'ecran LCD si besoin, sinon ne fait rien
  if(afficherTue) {
    if(millis() - timeStartedAffichageTue >= dureeAffichageTue) {
      afficherTue = false;
      needRefreshAll = true;
    }
  }
  affichage();

  if(true) {
    // Faire revivre si on est mort depuis suffisament logntemps
    // Pas besoin de check s'il nous reste des respawns, revivre le fait déja
    if(not(vivant) and (millis() - timeDeath >= r_timeRespawn))
      revivre();

    // Si cela fait plusieurs secondes que l'on a pas été touché, on reprend la vie EN COURS (par exemple si on a 2.4 / 5, on va regen jusqu'a 3/5)
    /*
    if((int(vie) != vie) and (millis() - timeLastBeingSemiShot >= r_timeStartSemiRegen)) {
      int viePrev = int(vie);
      vie += 0.01;
      if(vie >= viePrev)
        vie = int(vie);
    }*/
  }

  delay(4);
}



void menuCode() {
  
  // Rouge
  if((longueurCodeTape < 16) and checkButtonPress(2)) {
    codeTape[longueurCodeTape] = 2;
    longueurCodeTape++;
    needRefreshScore = true;
  }

  // Noir
  if((longueurCodeTape < 16) and checkButtonPress(3)) {
    codeTape[longueurCodeTape] = 3;
    longueurCodeTape++;
    needRefreshScore = true;
  }

  // Bleu
  if((longueurCodeTape < 16) and checkButtonPress(0)) {
    codeTape[longueurCodeTape] = 0;
    longueurCodeTape++;
    needRefreshScore = true;
  }

  // Validation
  if(checkButtonPress(1)) {
    bool same = (longueurCodeTape == 11);
    for(int i=0; i<longueurCodeTape; i++) {
      if(code[i] != codeTape[i]) same = false;
    }

    if(same) {
      inAdminMenu = true;
      inCodeMenu = false;
      longueurCodeTape = 0;
    }
    else {
      admin = false;
      inAdminMenu = false;
      inCodeMenu = false;
      longueurCodeTape = 0;
    }

    needRefreshAll = true;
  }
}


void stopperPartie() {
  started = false;

  // Reset cheats and rights
  admin = false;
  invincible = false;
  munitions_illim = false;
  rapidFire = false;

  // ARRETER LA PARTIE
  EEPROM.write(100, 0);

  // ADMIN rights
   EEPROM.write(189, 0); // false

   // Cheats
   EEPROM.write(190, invincible);
   EEPROM.write(191, munitions_illim);
   EEPROM.write(192, rapidFire);

   EEPROM.commit();
  needRefreshAll = true;
}

void stopAll() { 
  myData.idMessage = 30;
  myData.value = 2;
  uint8_t adressGuns[] = {0x32, 0x32, 0x32, 0x32, 0x32, 0x00};
  
  for(int j=0; j<redondanceEnvoi; j++) {
    for(int p=1; p<=9; p++) {
      if(p != player) {
        adressGuns[5] = p; 
        esp_now_send(adressGuns, (uint8_t *) &myData, sizeof(myData));
        delay(delaiEnvoi);
      }
      verifierConnexion();
    }
  }

  stopperPartie();
}

void menuAdmin() {
  do {
    if(connectedCibleAvant or connectedCibleArriere) { if(chooseBinary("Deconnecter ?", false)) deconnecter(); }
    if((started) and admin) { if(chooseBinary("Stop all ?", false)) stopAll();  }
    if(started) { if(chooseBinary("Stop individuel ?", false)) stopperPartie(); }
    if(chooseBinary("Devenir admin ?", admin)) {
        admin = true;
        EEPROM.write(189, 1);
        EEPROM.commit();
    }
    if (admin) { if(chooseBinary("Use cheats ?", false)) chooseCheats(); }
  } while (!(chooseBinary("Quitter menu ?", true)));

  needRefreshAll = true;
  inAdminMenu = false;
  inCodeMenu = false;
  enteringCodeMenu = false;
}


void chooseCheats() {
  r_timeRespawn      = 1000 *  chooseValue("Duree de la mort", r_timeRespawn/1000, 1, "s");
  r_nbRespawns       = 1    *  chooseValue("Nb. de respawns ", r_nbRespawns, 1, "");
  r_nbMortsDefinitives = 1   * chooseValue("Nb. morts defs  ", r_nbMortsDefinitives, 1, "");
  bool new_light_on           =        chooseBinary("Gilet allumé ?", light_on);
  if(new_light_on != light_on) { sendParametersCibles(); sendSingleTimeParametersCibles(); light_on = new_light_on; }
  invincible           =        chooseBinary("Invincible ?", invincible);
  munitions_illim           =        chooseBinary("Mun. illimités ?", munitions_illim);
  rapidFire           =        chooseBinary("Tir rapide ?", rapidFire);
  if(started) { if(chooseBinary("OS adversaires ?", false)) doom(); }

  
   vie = r_viesMax;
   respawnsRestants = min(r_nbRespawns, uint8_t(254)) + 1;
   if(munitions_illim) munitions = munitionsMax[weapon];

   // ADMIN rights
   EEPROM.write(189, 1); // true

   // Cheats
   EEPROM.write(190, invincible);
   EEPROM.write(191, munitions_illim);
   EEPROM.write(192, rapidFire);

   // Regles
   EEPROM.write(193, r_nbRespawns);
   EEPROM.write(194, r_nbMortsDefinitives);
   EEPROM.write(195, r_timeRespawn);
   EEPROM.write(197, light_on);

   // Etat partie
   EEPROM.write(198, vie);
   EEPROM.write(199, respawnsRestants);
   EEPROM.write(200, nb_fois_pistolet_eteint);

   EEPROM.commit();
   needRefreshAll = true;
}


void doom() {
  myData.idMessage = 60;
  myData.value = hue;
  uint8_t adressGuns[] = {0x32, 0x32, 0x32, 0x32, 0x32, 0x00};
  
  for(int j=0; j<redondanceEnvoi; j++) {
    for(int p=1; p<=9; p++) {
      if(p != player) {
        adressGuns[5] = p; 
        esp_now_send(adressGuns, (uint8_t *) &myData, sizeof(myData));
        delay(delaiEnvoi);
      }
      verifierConnexion();
    }
  }
}

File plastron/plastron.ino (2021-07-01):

#define FASTLED_ESP8266_RAW_PIN_ORDER
#include <FastLED.h>


#define AVANT 1
#define ARRIERE 2





 


#define NUM_LEDS 9
CRGB leds[NUM_LEDS];
const uint16_t ledPin = 4;
uint8_t hue = 0;
uint8_t hueBase = 0;

#define TIME_TO_CONFIRM_CONNECTION 5000 // Temps qu'a le pistolet pour confirmer la connexion
#define BLEEP_TIME_WAITING_TO_CONNECT 400 // Temps entre chaque changement d'état en attentant la connexion (la période vaut donc x2)
#define BLEEP_TIME_WAITING_TO_CONFIRM_CONNECTION 140 // Temps entre chaque changement d'état en attentant la confirmation de la connexion (la période vaut donc x2)
#define TIME_TURN_IN_GAME 500 // Temps pour faire un tour complet des leds lorsqu'une partie est en cours

#define TIME_WAIT_MAX_CHECK_CONNECTION 750

long timeConnectionProcessStarted = 0;
uint8_t adressPistolet[] = {0xF4, 0xCF, 0xA2, 0x00, 0x00, 0x00};
uint8_t addressPistoletSecondaire[] = {0xF4, 0xCF, 0xA2, 0x00, 0x00, 0x00};
uint8_t addressSelf[] = {0x8C, 0xAA, 0xB5, 0x78, 0x78, 0x8C};
uint8_t adressAutreCible[] = {0x84, 0xCC, 0xA8, 0x84, 0x3D, 0x18};
uint8_t addressReceived[] = {0xF4, 0xCF, 0xA2, 0x00, 0x00, 0x00};
bool connected = false;
bool hasBeenConnected = false;
bool tryingToConnect = false;
bool tryingToReconnect = false;
uint8_t typeCible = AVANT; // AVANT
bool ledBlinkState = false;
uint32_t lastConnectionCheck = 0;
bool equipeChosen = false;
bool besoinDeFaireAnimationMort = false;
bool light_on = true;

// For led chips like WS2812, which have a data line, ground, and power, you just
// need to define DATA_PIN.  For led chipsets that are SPI based (four wires - data, clock,
// ground, and power), like the LPD8806 define both DATA_PIN and CLOCK_PIN
// Clock pin only needed for SPI based chipsets when not using hardware SPI





#include <Arduino.h>
#include <IRremoteESP8266.h>
#include <IRrecv.h>
#include <IRutils.h>

// An IR detector/demodulator is connected to GPIO pin 14(D5 on a NodeMCU
// board).
// Note: GPIO 16 won't work on the ESP8266 as it does not have interrupts.
const uint16_t kRecvPin = 2;
//const uint16_t led = 4;

bool vivant = true;
long lastDeath = 0;
long timeRespawn = 1000;
bool partieEnCours = false;
long delai = 20;

long timeTurn = 500;
int currentLed = 0;
long lastUpdateLed = 0;
int nbLed = 2;

IRrecv irrecv(kRecvPin);

decode_results results;

#include <EEPROM.h>
#include <ESP8266WiFi.h>
#define EEPROM_SIZE 25
#include <espnow.h>


const uint8_t led1 = 14;
const uint8_t led2 = 12;
const uint8_t led3 = 13;

// REPLACE WITH RECEIVER MAC Address

uint8_t id = 0;

// Structure example to send data
// Must match the receiver structure
typedef struct struct_message {
  uint8_t idMessage;
  uint32_t value;
} struct_message;

// Create a struct_message called myData
struct_message myData;





void deconnecter() {
  // On déconnecte en mettant toutes les variabels a False
  connected = false;
  hasBeenConnected = false;
  tryingToConnect = false;
  tryingToReconnect = false;
  lastConnectionCheck = 0;
  timeConnectionProcessStarted = 0;

  // On efface l'adresse du pistolet
  for(int i=0; i<6; i++)
    EEPROM.write(12+i, 0);
  EEPROM.commit();
  adressPistolet[5] = 0;
}


void turnOn() {
  for(int i=0; i<NUM_LEDS; i++)
    leds[i] = CHSV(hue,255,255);

  FastLED.show();
}

void turnOff() {
  for(int i=0; i<NUM_LEDS; i++)
    leds[i] = CHSV(0,0,0);

  FastLED.show();
}


void mourir() {
  Serial.println("MOURIR");
  besoinDeFaireAnimationMort = true;
  vivant = false;
  digitalWrite(led2, LOW);
  Serial.println("MORT TERMINEE");
}


void animationMort() {
  for(int sat=255; sat>180; sat-=3) {
    for(int i=0; i<NUM_LEDS; i++)
      leds[i] = CHSV(hue,sat,255);
  
    FastLED.show();
    delay(6);
  }
  turnOff();
  besoinDeFaireAnimationMort = false;
}


void revivre() {
  vivant = true;
  if(light_on)
    turnOn();
  else
    turnOff();
  lastUpdateLed = millis();
  currentLed = NUM_LEDS-1;
  digitalWrite(led2, HIGH);

  // On vide le buffer de messages IR pour ne pas mourir instantanément
  while (irrecv.decode(&results)) {
    irrecv.resume();
  }
}

int numeroLed(int i){
  if (i<0)
    return i+NUM_LEDS;
  else if (i>=NUM_LEDS)
    return i-NUM_LEDS;
  return i;
}


void checkRestoreConnection() { 
  // On ajoute le pistolet comme destinataire et on lui envoie une confirmation de connexion
  esp_now_add_peer(adressPistolet, ESP_NOW_ROLE_COMBO, 1, NULL, 0);
  myData.idMessage = 4; // ID pour dire qu'on demande a se connecter
  myData.value = hueBase; // on envoie la couleur de la cible
  esp_now_send(adressPistolet, (uint8_t *) &myData, sizeof(myData));

  tryingToReconnect = true;

  myData.idMessage = 13; // ID pour dire qu'on demande si l'autre cible est connectée
  myData.value = 0; //(pas de valeur);
  esp_now_send(adressAutreCible, (uint8_t *) &myData, sizeof(myData));
}



void touche(uint32_t message) {
  // Les messages du laser game finissent par 0x66
  // Si ce n'est as le cas, on ignore le message
  uint32_t checkLaserGame = message % uint32_t(pow(16,3));
  Serial.println("TOUCHE");

  if(connected)
    checkLaserGame = uint32_t(0x866);
    
  if (checkLaserGame == uint32_t(0x866)) {
    message -= message % uint32_t(pow(16,3));
    uint32_t uintAddress = message;
    Serial.println("Laser Game checked");

    uint8_t address[] = {0x32, 0x32, 0x32, 0x32, 0x32, 0x00};


    uint8_t nbBytesMAC = 1;
    for(int i=0; i<nbBytesMAC; i++) {
      uint32_t adressPart = uint32_t(uint32_t(message % uint32_t(pow(16,10-2*nbBytesMAC+2*i)) / pow(16,8-2*nbBytesMAC+2*i)));
      address[5-i] = uint8_t(adressPart);
      message -= adressPart * pow(16,8-2*nbBytesMAC+2*i);
    }

    if((not(connected)) and (typeCible == AVANT) and not(hasBeenConnected)) {
      // On copie l'adresse du pistolet
      for(int i=0; i<6; i++)
        adressPistolet[i] = address[i];
        
      // On ajoute le pistolet comme destinataire et on lui envoie une confirmation de connexion
      esp_now_add_peer(adressPistolet, ESP_NOW_ROLE_COMBO, 1, NULL, 0);
      myData.idMessage = 1; // ID pour dire qu'on demande a se connecter
      myData.value = hueBase; // on envoie la couleur de la cible
      esp_now_send(adressPistolet, (uint8_t *) &myData, sizeof(myData));

      // On commence à compter, on a 10s pour confirmer la connexion
      tryingToConnect = true;
      timeConnectionProcessStarted = millis();
    }
    else if(connected) {
      // On envoie au pistolet qu'on a été touché
      myData.idMessage = 10; // ID pour dire qu'on a été touché
      myData.value = uintAddress + typeCible; // 1 = cible avant, 2 = cible arriere
      esp_now_send(adressPistolet, (uint8_t *) &myData, sizeof(myData));
    }
  }
}
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

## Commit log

2021-01-28 [ADD] Ajout de tous les messages WiFi + gestion des leds"
2021-02-24 [ADD] Gestion de toute la connexion avec reconnexion automatique + choix de l'equipe, validation et a nouveau recuperationd e l'equipe selectionner en cas d'extinction
2021-05-11 [MODIF] Changement de la reception du signal pour augmenter la portée (mais on ne peux plus identifier le tueur)
2021-05-11 [ADD] Ajout du choix des paramètres, simplification de la connexion, et debut d'une partie
2021-05-11 [MODIF] Stabilisation de la connexion
2021-05-12 [MODIF] Ajout du mode light off et resolution de problemes de connexion
    [gun.ino, plastron.ino]
2021-06-14 [ADD] Début de l'ajout du mode administrateur + déconnexion possinle
2021-06-21 [ADD] Ajout des ressources secondaires (PCBs, SolidWorks, Sounds, Pictures)
    [19_01_pistolet_cote_circuit.STL, 19_01_pistolet_cote_rien.STL, 27_pistolet_cote_rien.STL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]
